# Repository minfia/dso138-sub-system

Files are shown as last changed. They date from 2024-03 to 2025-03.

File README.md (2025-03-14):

# DSO138 Sub System
DSO138の操作を少し楽にする"なにか"。

## 1. 環境
|  No.  | 名称 | バージョン | 備考 |
| :---: | --- | --- | --- |
| 1 | Microchip Studio | 7.0.2594 | |
| 2 | ATmega_DFP | 2.0.401 | |
| 3 | KiCad | 7.0.6 | 回路図の一部は[自作](https://github.com/minfia/kicad-library) |

## 2. FUSEビット設定
| ビット名 |  値 |
| --- | :---: |
| EXTENDED | 0xF9  |
| HIGH | 0xDC  |
| LOW | 0xE2  |

## 3. ビルド
1. `dso138_sub_system.atsln`をダブルクリック
1. `F7`を押下

## 4. ケースについて
一部目測による箇所があります。\
そのため基板と実際に出力されたケースの寸法が違う場合があります。

また、ケースの出力は遊舎工房様に[依頼](https://shop.yushakobo.jp/products/lasercut)したものになります。\
そのため、デザインファイル(`.svg`)は遊舎工房様向けとなっております。

## 5. ボタンの色詳解
|  No.  | 色  | 機能 |
| :---: | --- | --- |
| 1 | 赤  | OK |
| 2 | 黄  | 掃引時間 |
| 3 | 黄  | エッジ切り替え |
| 4 | 黄  | トリガーレベル |
| 5 | 黄  | 時間軸移動 |
| 6 | 黄  | 電圧移動 |
| 7 | 緑  | トリガー(auto) |
| 8 | 緑  | トリガー(signal) |
| 9 | 青  | 波形保存 |
|  10 | 青  | 波形読み出し |

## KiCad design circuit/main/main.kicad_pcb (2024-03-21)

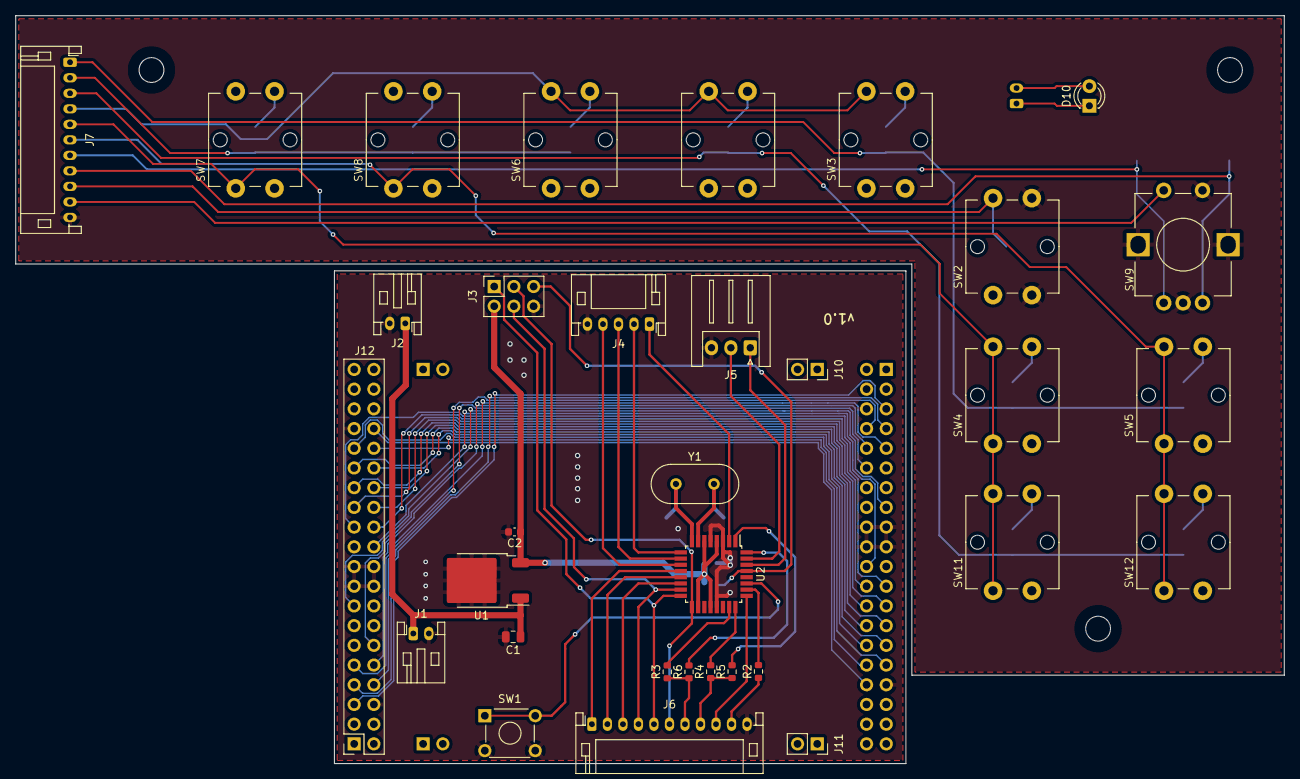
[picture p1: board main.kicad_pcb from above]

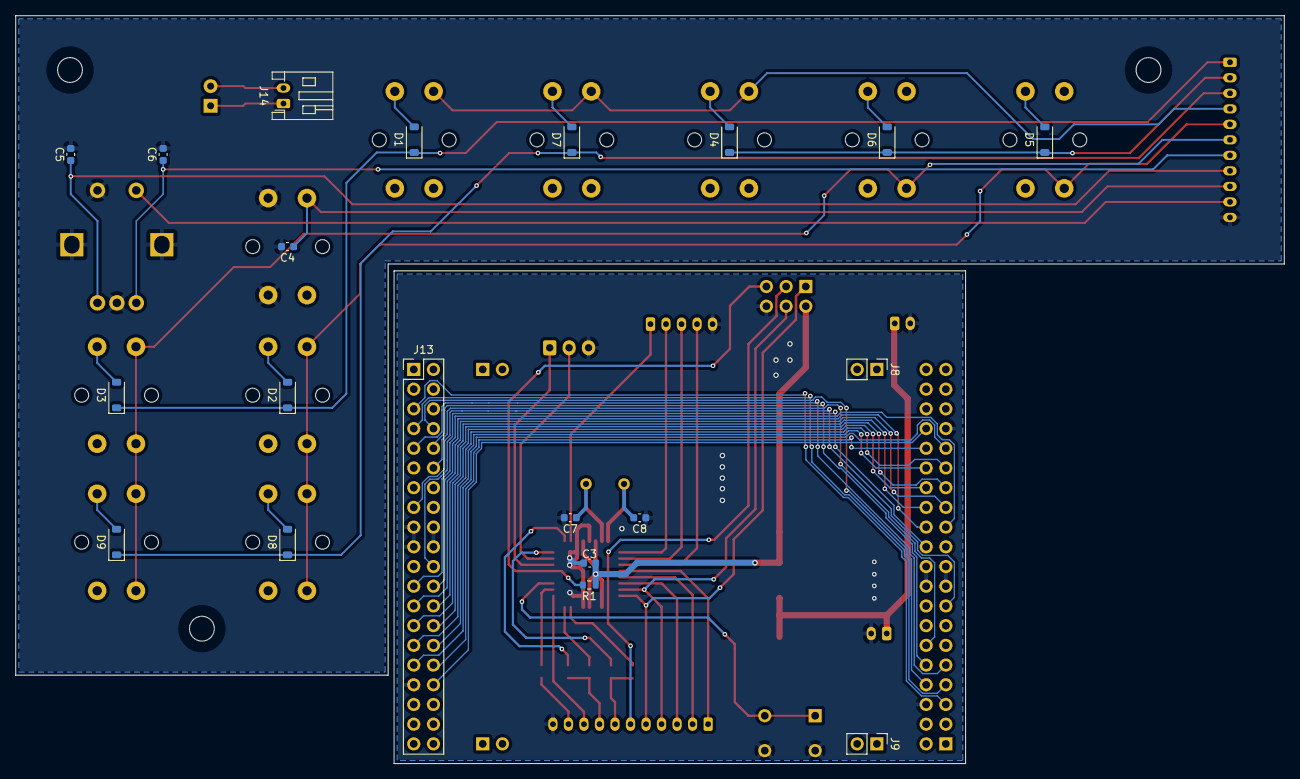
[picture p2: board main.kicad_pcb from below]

Board: 2 copper layers, 163.5 x 96.4 mm, 53 parts (20 on the bottom side), 69 nets.

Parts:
C1: 0.33uF; C_0805_2012Metric
C2: 2.2uF; C_0603_1608Metric
C3, C4, C5, C6: 0.1uF; C_0603_1608Metric
C7, C8: 22pF; C_0603_1608Metric
D1, D2, D3, D4, D5, D6, D7, D8, D9: 1N4148; D_SOD-123
D10: LED; LED_D3.0mm
J1, J2, J14: Conn_01x02; JST_PH_S2B-PH-K_1x02_P2.00mm_Horizontal
J3: AVR-ISP-6; PinSocket_2x03_P2.54mm_Vertical
J4: PH-1x5pin_Horizontal; JST_PH_S5B-PH-K_1x05_P2.00mm_Horizontal
J5: XH-1x3pin_Horizontal; JST_XH_S3B-XH-A_1x03_P2.50mm_Horizontal
J6, J7: PH-1x11pin_Horizontal; JST_PH_S11B-PH-K_1x11_P2.00mm_Horizontal
J8, J9: Conn_01x02; PinHeader_1x02_P2.54mm_Vertical
J10, J11: Conn_01x02; PinSocket_1x02_P2.54mm_Vertical
J12: Conn_02x20_Odd_Even; PinSocket_2x20_P2.54mm_Vertical
J13: Conn_02x20_Odd_Even; PinHeader_2x20_P2.54mm_Vertical
R1: 10k; R_0603_1608Metric
R2: 100; R_0603_1608Metric
R3, R4, R5, R6: 0; R_0603_1608Metric
SW1: SW_MEC_5E; SW_TH_Tactile_Omron_B3F-10xx
SW2: KC-901TC-R
SW3, SW6, SW7, SW8, SW10: KC-901TC-Y
SW4, SW5: KC-901TC-G
SW9: EC12PLxVF; EC12-020
SW11, SW12: KC-901TC-BU
U1: NJM2845DL1-05; TO-252-2
U2: ATmega328P-A; TQFP-32_7x7mm_P0.8mm
Y1: 16MHz; Crystal_HC18-U_Vertical

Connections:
+5V: C2.1, C3.1, J3.2 (VCC), R1.1, U1.3 (VOUT), U2.4 (VCC), U2.6 (VCC), U2.18 (AVCC), U2.20 (AREF)
+9V: C1.1, J1.1, J2.1, U1.1 (VIN)
GND: C1.2, C2.2, C3.2, C7.2, C8.2, J1.2, J2.2, J3.6 (GND), J4.5, J5.3, J6.11, J12.6, J12.17, J12.18, J12.19, J12.20, J12.33, J13.6, J13.17, J13.18, J13.19, J13.20, J13.33, SW1.2, U1.2 (GND), U2.3 (GND), U2.5 (GND), U2.21 (GND)
GND1: C4.2, C5.2, C6.2, J7.11, SW2.3 (K), SW2.4 (A), SW9.-, SW9.C, SW9.GND
unnamed: D1.2 (A), SW3.4 (A)
unnamed: D1.1 (K), D2.1 (K), D3.1 (K), J7.1
unnamed: D2.2 (A), SW4.4 (A)
unnamed: D3.2 (A), SW5.4 (A)
unnamed: D4.2 (A), SW6.4 (A)
unnamed: D4.1 (K), D5.1 (K), D6.1 (K), J7.2
unnamed: D5.2 (A), SW7.4 (A)
unnamed: D6.2 (A), SW8.4 (A)
unnamed: D7.2 (A), SW10.4 (A)
unnamed: D7.1 (K), D8.1 (K), D9.1 (K), J7.3
unnamed: D8.2 (A), SW11.4 (A)
unnamed: D9.2 (A), SW12.4 (A)
unnamed: D10.2 (A), J14.2
unnamed: D10.1 (K), J14.1
unnamed: J3.1 (MISO), J6.5, U2.16 (PB4)
unnamed: J3.4 (MOSI), J6.4, U2.15 (PB3)
unnamed: J3.3 (SCK), J6.6, U2.17 (PB5)
unnamed: J3.5 (~RST), R1.2, U2.29 (~RESET/PC6)
unnamed: J4.1, U2.2 (PD4)
unnamed: J4.2, U2.9 (PD5)
unnamed: J4.3, U2.10 (PD6)
unnamed: J4.4, U2.11 (PD7)
unnamed: J5.1, U2.30 (PD0)
unnamed: J5.2, U2.31 (PD1)
unnamed: J6.1, U2.12 (PB0)
unnamed: J6.2, U2.13 (PB1)
unnamed: J6.3, U2.14 (PB2)
unnamed: J6.7, R3.1, R6.1
unnamed: J6.8, R4.1, R5.1
unnamed: J6.9, U2.25 (PC2)
unnamed: J6.10, R2.1
unnamed: J7.4, SW3.2, SW6.2, SW10.2
unnamed: J7.5, SW4.1, SW4.2, SW7.1, SW11.1, SW11.2
unnamed: J7.6, SW5.1, SW5.2, SW8.1, SW12.1, SW12.2
unnamed: C6.1, J7.7, SW9.A
unnamed: C5.1, J7.8, SW9.B
unnamed: C4.1, J7.9, SW2.2
unnamed: J7.10, SW9.+
unnamed: J12.5, J13.5
unnamed: J12.7, J13.7
unnamed: J12.8, J13.8
unnamed: J12.9, J13.9
unnamed: J12.10, J13.10
unnamed: J12.12, J13.12
unnamed: J12.15, J13.15
unnamed: J12.22, J13.22
unnamed: J12.23, J13.23
unnamed: J12.24, J13.24
unnamed: J12.25, J13.25
unnamed: J12.26, J13.26
unnamed: J12.27, J13.27
unnamed: J12.28, J13.28
unnamed: J12.29, J13.29
unnamed: J12.30, J13.30
unnamed: J12.31, J13.31
unnamed: J12.32, J13.32
unnamed: J12.34, J13.34
unnamed: R3.2, U2.23 (PC0)
unnamed: R4.2, U2.24 (PC1)
unnamed: R2.2, U2.26 (PC3)
unnamed: SW1.1, U2.27 (PC4)
unnamed: R6.2, U2.32 (PD2)
unnamed: R5.2, U2.1 (PD3)
unnamed: C7.1, U2.7 (XTAL1/PB6), Y1.2
unnamed: C8.1, U2.8 (XTAL2/PB7), Y1.1

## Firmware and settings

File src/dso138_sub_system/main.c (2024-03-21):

/**
 * @file    main.c
 * @brief   main
 *
 * @author  minfia
 */ 

#include <avr/io.h>
#include <avr/interrupt.h>
#include <stddef.h>
#include "system.h"
#include "driver/systick.h"
#include "driver/port.h"
#include "driver/timer.h"
#include "driver/eeprom.h"
#include "device/rotary_encoder.h"
#include "device/key_matrix.h"
#include "device/dso138.h"
#include "application/key_matrix.h"


/**
 * @brief   キー入力とDSO138処理の紐づけ
 */
typedef struct {
    INPUT_KEY_TYPE key;                                 //!< キー入力
    DSO138_MODE_STATE state;                            //!< DSO138ステート
    void (*state_func)(DSO138_MODE_STATE next_state);   //!< ステート遷移関数ポインタ
    void (*option_func)(void);                          //!< ステート遷移以外の関数ポインタ
} KEY_DSO138_STATE_DIC;

static const KEY_DSO138_STATE_DIC key_state[] = {
    { INPUT_KEY_TYPE_0_0,   DSO138_MODE_STATE_CHANGE_EDGE,          dso138_change_state,    NULL                }, // SW3
    { INPUT_KEY_TYPE_0_1,   DSO138_MODE_STATE_TRIG_AUTO,            dso138_change_state,    NULL                }, // SW4
    { INPUT_KEY_TYPE_0_2,   DSO138_MODE_STATE_TRIG_SIGNAL,          dso138_change_state,    NULL                }, // SW5
    { INPUT_KEY_TYPE_1_0,   DSO138_MODE_STATE_VERTICAL_POS,         dso138_change_state,    NULL                }, // SW6
    { INPUT_KEY_TYPE_1_1,   DSO138_MODE_STATE_TIME_BASE,            dso138_change_state,    NULL                }, // SW7
    { INPUT_KEY_TYPE_1_2,   DSO138_MODE_STATE_CHANGE_TRIG_LEVEL,    dso138_change_state,    NULL                }, // SW8
    { INPUT_KEY_TYPE_2_0,   DSO138_MODE_STATE_HORIZONTAL_POS,       dso138_change_state,    NULL                }, // SW10
    { INPUT_KEY_TYPE_2_1,   DSO138_MODE_STATE_MAX,                  NULL,                   dso138_save_wave    }, // SW11
    { INPUT_KEY_TYPE_2_2,   DSO138_MODE_STATE_MAX,                  NULL,                   dso138_load_wave    }, // SW12
};


int main(void)
{
    systick_init();
    port_init();
    eeprom_init();
    rotary_enc_init();
    app_key_matrix_init();
    {
        DSO138_BUTTON_t button;
        button.ok.port = &PORTD;
        button.ok.num = 4;
        button.plus.port = &PORTD;
        button.plus.num = 5;
        button.minus.port = &PORTD;
        button.minus.num = 6;
        button.sel.port = &PORTD;
        button.sel.num = 7;
        dso138_init(button);
    }
    timer0_start();
    sei();

    while (1) {
        // キー入力処理
        if (0 == port_get(&PINC, 4)) {
            // 設定記憶リセット
            eeprom_reset();
        }
        if (0 == port_get(&PINC, 2)) {
            dso138_press_ok_button();
        } else {
            dso138_release_ok_button();
            app_key_matrix_poll();
            INPUT_KEY_TYPE key = app_key_matrix_get_key_type();
            for (int i=0; i<sizeof(key_state)/sizeof(KEY_DSO138_STATE_DIC); i++) {
                if (key_state[i].key == key) {
                    if ((DSO138_MODE_STATE_MAX != key_state[i].state) && (NULL != *key_state[i].state_func)) {
                        key_state[i].state_func(key_state[i].state);
                    } else if (NULL != *key_state[i].option_func) {
                        key_state[i].option_func();
                    }
                }
            }
            // ロータリーエンコーダの回転方向を取得
            ROTARY_ENCODER_ROTATE_STATE state = rotary_enc_get_state();
            /**
             * @note 時間軸移動のみスクロールバーがロータリーエンコーダの回転と逆の動きをするため\n
             *       時間軸移動では+と-を反転させる\n
             *       また、トリガーレベルの場合1回押下では移動しないため2回押下を行う
             */
            if (ROTARY_ENCODER_ROTATE_STATE_CW == state) {
                switch (dso138_get_state()) {
                    case DSO138_MODE_STATE_CHANGE_TRIG_LEVEL:
                        dso138_enter_plus_key(2);
                        break;
                    default:
                        dso138_enter_plus_key(1);
                        break;
                }
            } else if (ROTARY_ENCODER_ROTATE_STATE_CCW == state) {
                switch (dso138_get_state()) {
                    case DSO138_MODE_STATE_CHANGE_TRIG_LEVEL:
                        dso138_enter_minus_key(2);
                        break;
                    default:
                        dso138_enter_minus_key(1);
                        break;
                }
            }
        }
    }
}

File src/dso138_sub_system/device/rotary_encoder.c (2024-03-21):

/**
 * @file    rotary_encoder.c
 * @~japanase
 * @brief   ロータリーエンコーダデバイスドライバ
 * @~
 * @brief   rotary encoder device driver.
 *
 * @author  minfia
 */ 

#include "rotary_encoder.h"


/**
 * @~japanese
 * @brief   回転方向
 * @~
 * @brief   direction of rotate.
 */
volatile static ROTARY_ENCODER_ROTATE_STATE rotate_state;

/**
 * @~japanese
 * @brief   A相B相の状態保持用
 * @~
 * @brief   Value of hold to status in signal A and signal B.
 */
volatile static uint8_t pin_history;


/**
 * @~japanese
 * @brief   1クリック分のビット遷移と回転方向の構造体
 * @~
 * @brief   Structs for bit transition in 1 click and direction of rotate.
 */
typedef struct {
    uint8_t state_val;
    ROTARY_ENCODER_ROTATE_STATE state_name;
} ROTARY_DIRECTION_t;

/**
 * @~japanese
 * @brief   正転/逆転と1クリック分の情報
 * @~
 * @brief   Information of CW/CCW and 1 click bits.
 */
 static const ROTARY_DIRECTION_t rotary_directions[] = {
    { 0b10000111, ROTARY_ENCODER_ROTATE_STATE_CW  },
    { 0b01001011, ROTARY_ENCODER_ROTATE_STATE_CCW }
};


void rotary_enc_init(void)
{
    rotate_state = ROTARY_ENCODER_ROTATE_STATE_NO_CHANGE;
    pin_history = 0;
}

void rotary_enc_regist_pin(uint8_t pin)
{
    pin_history <<= 2;
    pin_history |= pin;
    rotary_enc_calc_state();
}

void rotary_enc_calc_state(void)
{
    for (int i=0; i<sizeof(rotary_directions)/sizeof(rotary_directions[0]); i++) {
        if (rotary_directions[i].state_val == pin_history) {
            pin_history = 0;
            rotate_state = rotary_directions[i].state_name;
            return;
        }
    }
}

ROTARY_ENCODER_ROTATE_STATE rotary_enc_get_state(void)
{
    ROTARY_ENCODER_ROTATE_STATE state = rotate_state;
    rotate_state = ROTARY_ENCODER_ROTATE_STATE_NO_CHANGE;

    return state;
}

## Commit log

2023-02-12 add: DSO138を制御できる機能を一通り追加
2023-05-07 Change: マイコンのシリーズをATmega128からATmega328Pに変更
2024-03-21 fix: 回路に合わせて入出力を修正
2024-03-21 add: 回路のプロジェクトを追加
    [input_key.kicad_sch, lcd_sw.kicad_sch, main.kicad_pcb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]
2024-03-21 add: ケースのデザインデータを追加
2024-03-21 add: ライセンスファイルを追加
2024-03-21 docs: 情報追記
